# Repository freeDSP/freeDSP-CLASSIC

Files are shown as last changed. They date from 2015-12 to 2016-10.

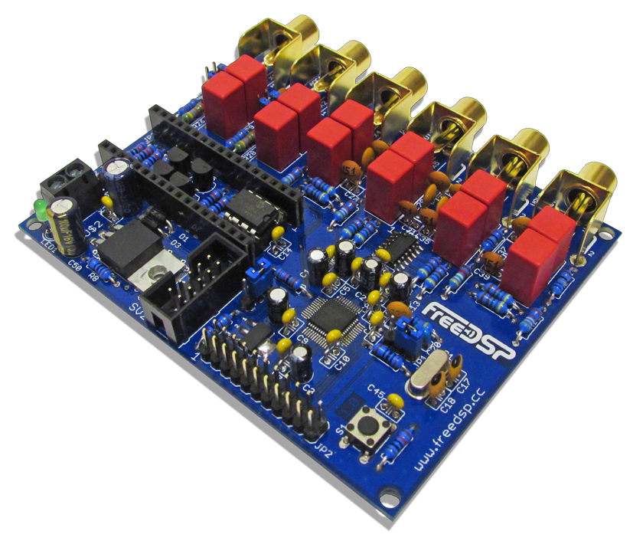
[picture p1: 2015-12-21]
DOCUMENTATION/PICTURES/freeDSP_1_0_side.png

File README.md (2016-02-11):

# freeDSP CLASSIC

BOARD STATUS: READY TO BE BUILT

MAIN COORDINATOR: [sudlud](https://github.com/sudlud)

The freeDSP CLASSIC is a cost-effective real-time audio signal processing solution for researchers and the do-it-yourself community. It is a bare circuit board that can be incorporated into your own projects. It comes with no housing. Easy assembling and simple programmability are the main focus. It is based on Analog Devices’ ADAU1701 DSP chip together with the free graphical development environment SigmaStudio. The programming model is function-block based – comparable to other graphical programming languages like PureData or Max/MSP. Many prebuilt blocks (e.g., filters, compressors, effects, or logic) can be placed in the signal path via drag and drop. If the included libraries do not have the functions needed, low-level blocks, such as multipliers and delays, can be wired together to create custom algorithms.

This board uses MAINLY THT components. The trickiest part is soldering the DSP, which comes in an SMD packaging. A complete SMD version is under development.

## Features

The freeDSP CLASSIC board offers two analog inputs and four analog outputs. Compared to other DSP solutions with easy programmability, the freeDSP and SigmaStudio offer a much wider range of DSP processing options and interface controls. It can be used in various audio applications, e.g.:

* Room compensation / system equalization
* Digital crossovers in active loudspeaker concepts
* Multiband dynamics processing
* Delay compensation / phase shift
* Bass enhancement
* Subwoofer integration
* Advanced instrument audio effect units
* Stereo image widening
…

For more information, please refer to the website www.freeDSP.cc and the documentation.  

## License

This work and all other materials under https://github.com/freeDSP are licensed under a <a rel="license" href="http://creativecommons.org/licenses/by-sa/4.0/legalcode">Creative Commons Attribution Share-Alike 4.0 license</a>. This allows for both personal and commercial derivative works, as long as they credit freeDSP and release their designs under the same license.

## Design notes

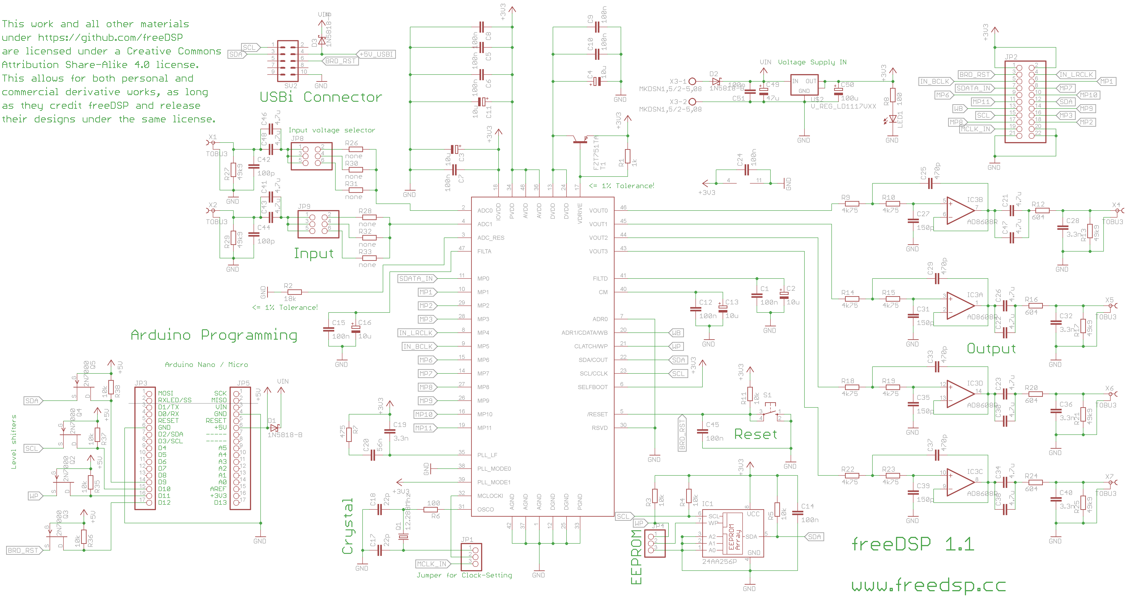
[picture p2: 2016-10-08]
SOURCES/EAGLE/SCHEMATIC_FREEDSP_V1_1_300dpi.png

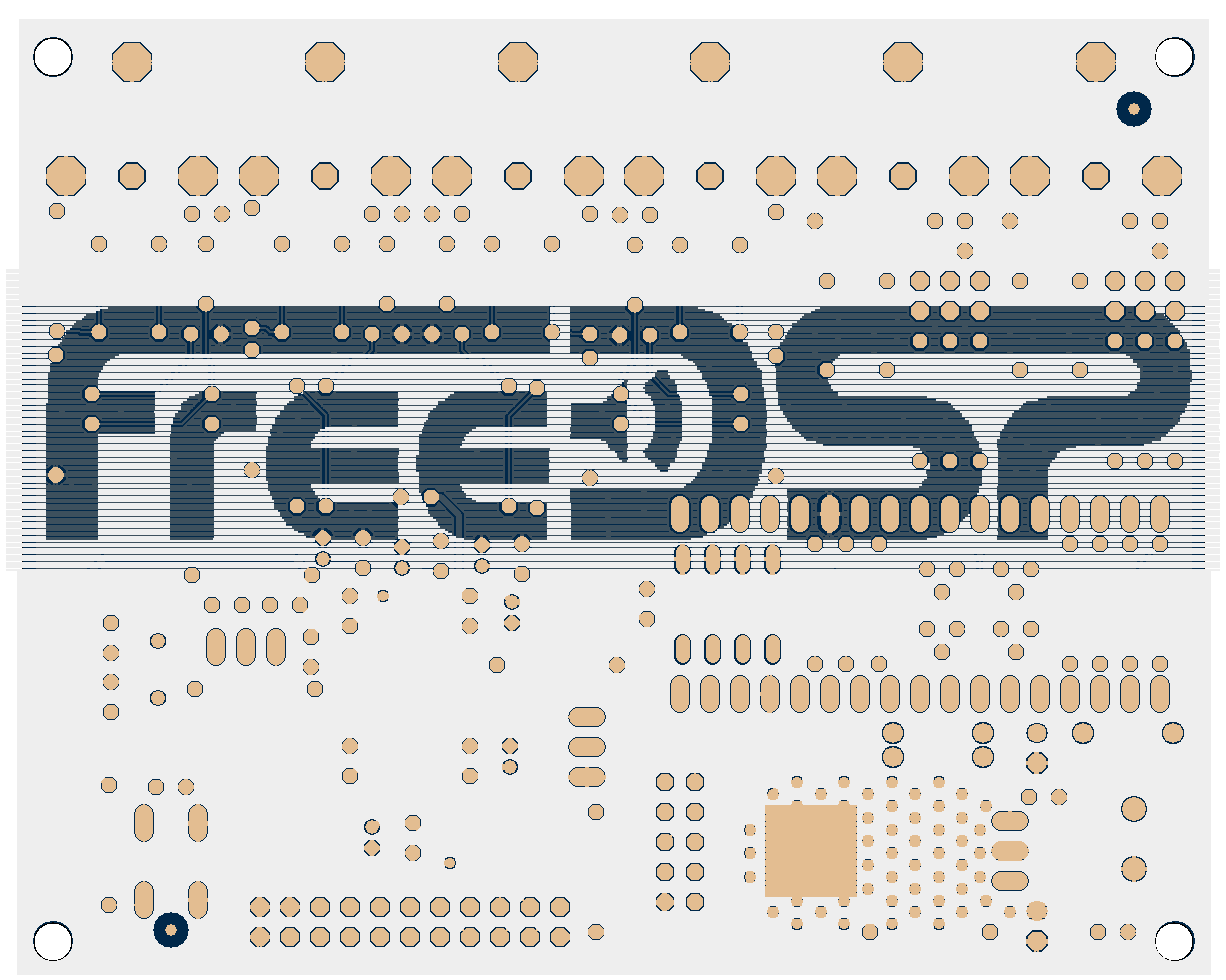
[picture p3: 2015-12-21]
DOCUMENTATION/PICTURES/back.png

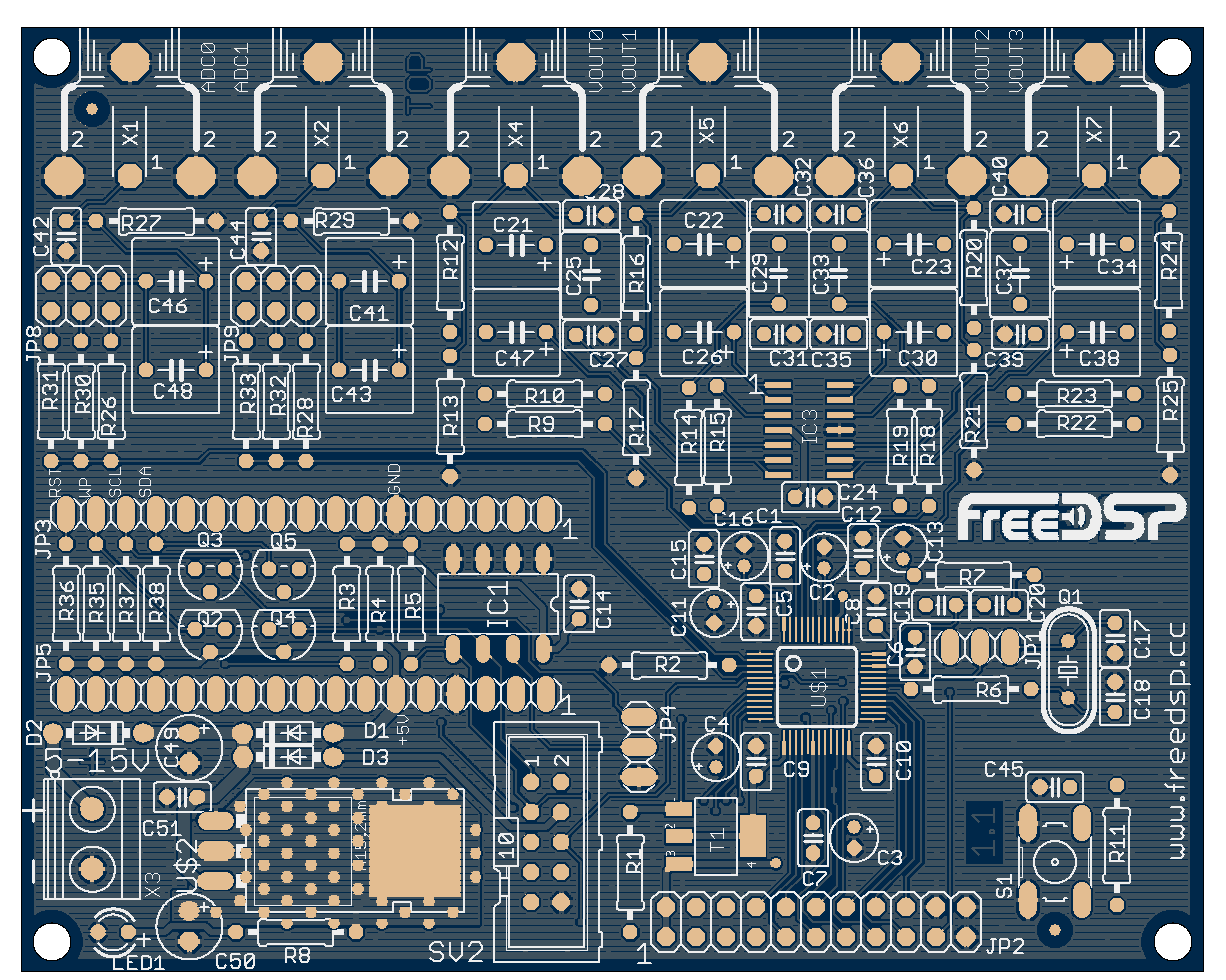
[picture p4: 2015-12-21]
DOCUMENTATION/PICTURES/front.png

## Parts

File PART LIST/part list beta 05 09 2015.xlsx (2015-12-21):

Part list |  |  |  | reichelt.de
Part | Description | Label | Qty. | Order number
C1, C5, C6, C7, C8, C9, C10, C12, C14, C15, C24, C45, C51 | Ceramic capacitor, 100nF | 104 | 13 | X7R-2,5 100N
C2, C3, C4, C11, C13, C16 | Electrolytic capacitor, radial, 10µF, 16V/50V | 10µF/16 | 6 | SM 10/16 RAD
C17, C18 | Ceramic capacitor, 22pF, 63V/200V | 22/100V | 2 | KERKO 22P
C19, C28, C32, C36, C40 | Ceramic capacitor, 3.3nF, 63V/50V | 332 | 5 | KERKO 3,3N
C20 | Ceramic capacitor, 56nF, 100V | green blue orange | 1 | not available
C21, C22, C23, C26, C30, C34, C38, C41, C43, C46, C47, C48 | Foil capacitor, 4.7µF | 4,7µF | 12 | MKS-2 4,7µ
C25, C29, C33, C37 | Ceramic capacitor, 470pF, 500V | 470 | 4 | KERKO-500 470P
C27, C31, C35, C39 | Ceramic capacitor, 150pF, 63V | 151 | 4 | KERKO 150P
C42, C44 | Ceramic capacitor, 100pF, 50V | 101 | 2 | KERKO 100P
C49 | Electrolytic capacitor, radial, 47µF, 35V | 47µF/35 | 1 | RAD 47/35
C50 | Electrolytic capacitor, radial, 100µF, 6.3V | 100µF/16 | 1 | RAD FC 100/16
D1, D2, D3 | Shottky diode, 1N5818, DO41, 30V, 1A | 1N5818 | 3 | 1N 5818
IC1a | EEPROM, serial, 256kBit, DIP-8 | 24AA256 | 1 | 24AA256-I/P
IC1b | IC socket, DIP8 (for EEPROM) | - | 1 | GS 8
IC3 | AD8608 | AD8608 | 1 | Order via DigiKey
JP1, JP4 | Multi-pin connector, 1x3, RM 2.54mm | - | 2 | MPE 087-1-003
JP2 | Multi-pin connector, 2x13, RM 2.54mm, needs to be shortened to 2x11 | - | 1 | SL 2x13G 2,54
JP3, JP5 | Plug connector, 1x20, RM 2.54mm, needs to be shortened to 1x17 | - | 2 | BL 1x20G8 2,54
JP8, JP9 | Multi-pin connector, 2x3, RM 2.54mm | - | 2 | MPE 087-2-006
LED1 | LED, 3mm, green | - | 1 | LED 3MM 2MA GN
Q1 | Quartz crystal, 12.288Mhz, HC49/U-S | - | 1 | 12,2880-HC49U-S
Q2, Q3, Q4, Q5 | n-MOSFET 2N7000 | - | 4 | 2N 7000
R1 | Resistor, 1kΩ | brown black black brown brown | 1 | METALL 1,00K
R2, R26, R28 | Resistor, 18kΩ | brown grey black red brown | 3 | METALL 18,0K
R3, R4, R5, R11, R35, R36, R37, R38 | Resistor, 10kΩ | brown black black red brown | 8 | METALL 10,0K
R6, R8 | Resistor, 100Ω | brown black black black brown | 2 | METALL 100
R7 | Resistor, 475Ω | yellow violet green black brown | 1 | METALL 475
R9, R10, R14, R15, R18, R19, R22, R23 | Resistor, 4.75kΩ | yellow violet green brown brown | 8 | METALL 4,75k
R12, R16, R20, R24 | Resistor, 604Ω | blue black yellow black brown | 4 | METALL 604
R13, R17, R21, R25, R27, R29 | Resistor, 49.9kΩ | yellow white white red brown | 6 | METALL 49,9K
R31, R33 | Resistor, 7.15kΩ | violet brown green brown brown | 2 | METALL 7,15K
R30, R32 | Resistor, 10.5kΩ | brown black green red brown | 2 | METALL 10,5K
S1 | Switch, 6x6mm, H: 4.3mm; 12V | - | 1 | TASTER 3301
SV2 | Boxed header, 10 pins | - | 1 | WSL 10G
T1 | Zetex PNP transistor | - | 1 | FZT 751TA
U1 | ADAU1701 | - | 1 | Order via DigiKey
U2 | LM1117 +3V3 voltage regulator | - | 1 | LM 1117 T3,3
X1, X2, X4, X5, X6, X7 | Cinch connector | - | 6 | CBP-G
JP1, JP4, JP8, JP9 | Jumper | - | 4 | JUMPER 2,54 BL
X3 | Terminal, 2x, 5.08mm grid | - | 1 | AKL 101-02

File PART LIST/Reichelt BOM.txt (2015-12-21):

http://www.reichelt.de/?ACTION=20;AWKID=1038022;PROVID=2084

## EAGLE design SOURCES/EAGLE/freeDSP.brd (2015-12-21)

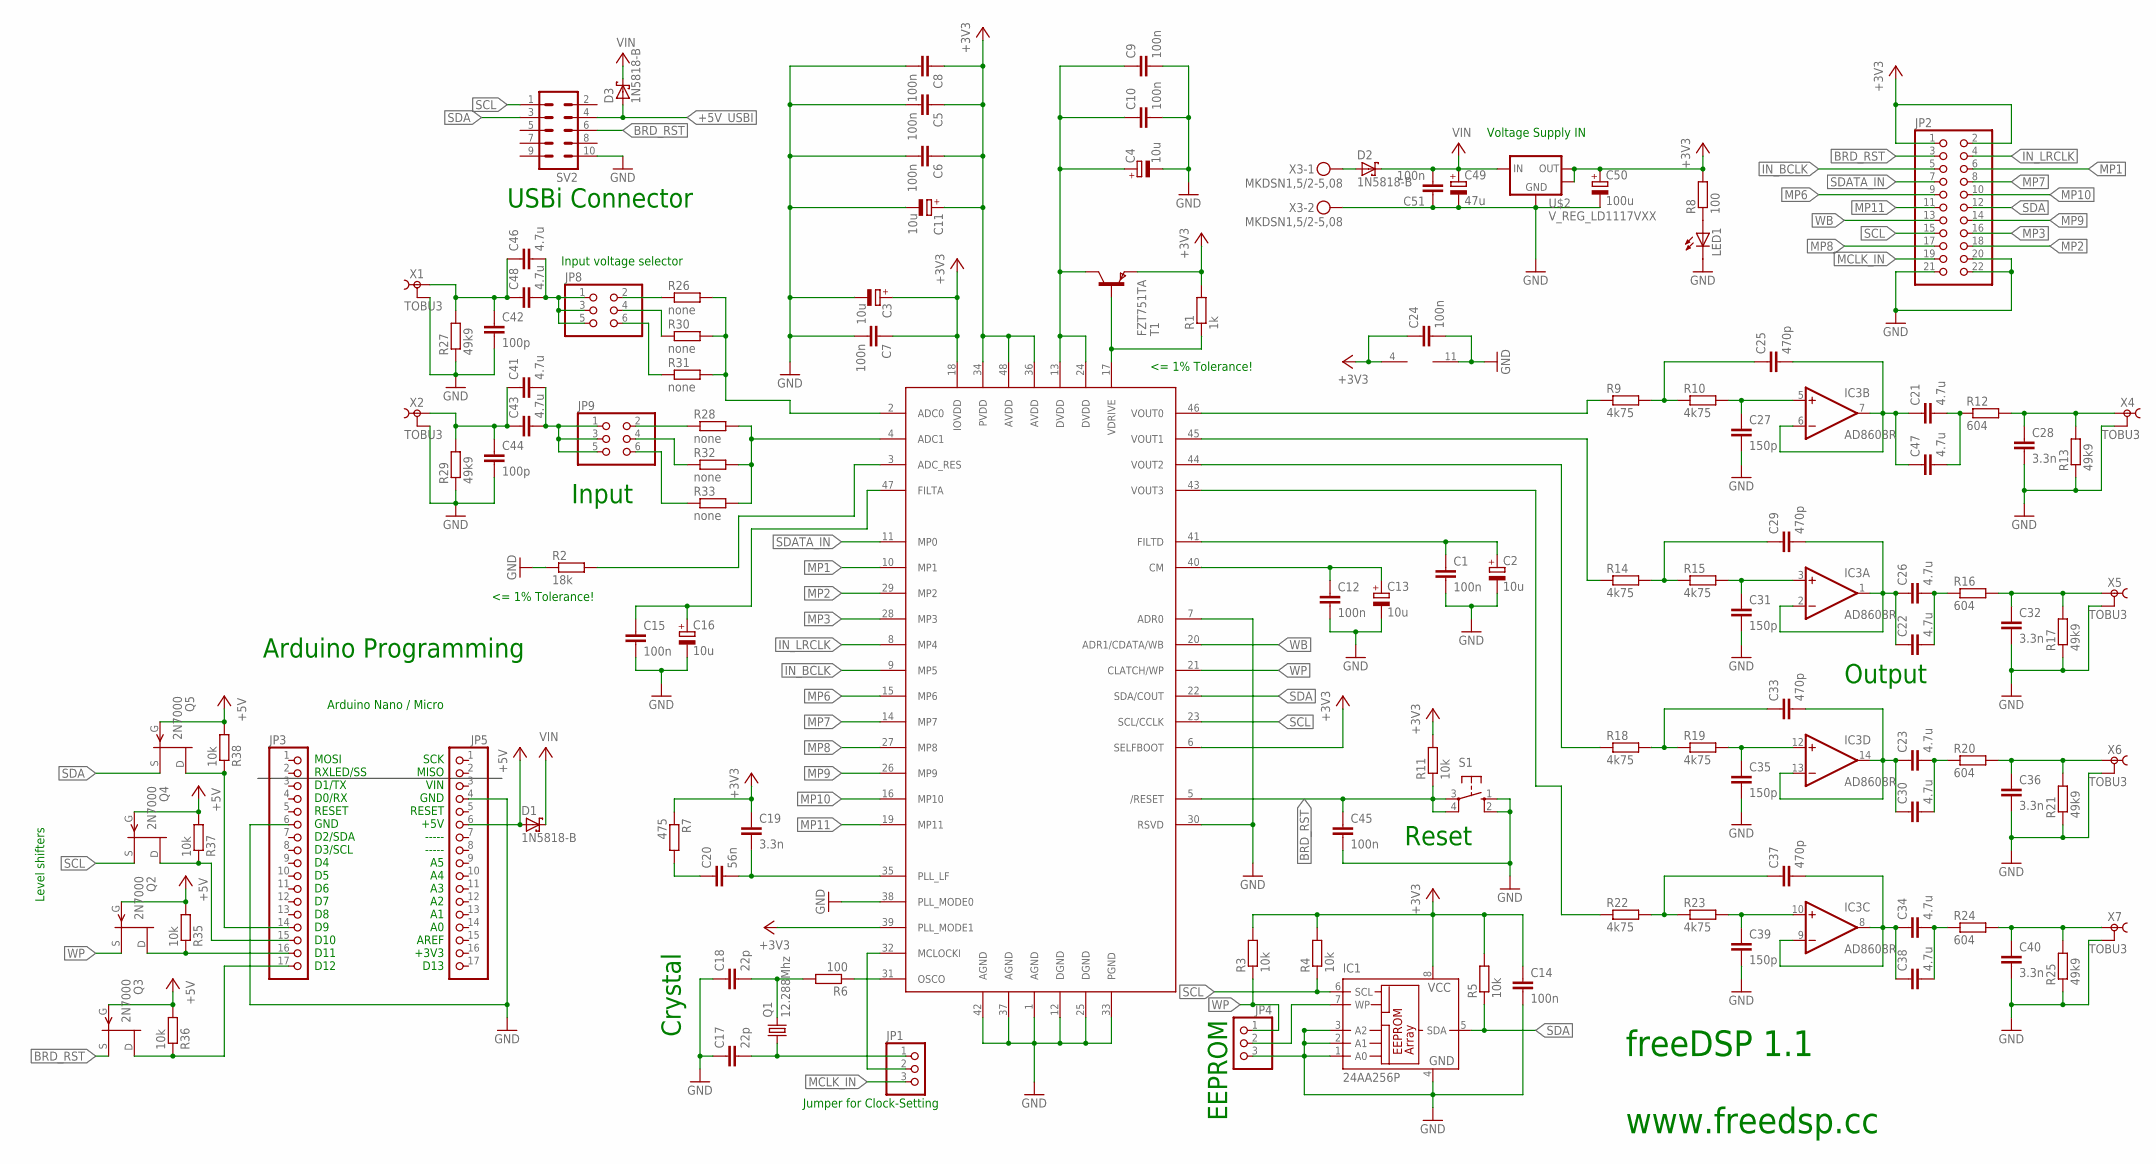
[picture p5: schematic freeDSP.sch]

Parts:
C1, C5, C6, C7, C8, C9, C10, C12, C14, C15, C24, C45, C51: 100n; C025-025X050
C2, C3, C4, C11, C13, C16: 10u; E1,8-4
C17, C18: 22p; C025-025X050
C19, C28, C32, C36, C40: 3.3n; C025-025X050
C20: 56n; C025-025X050
C21, C22, C23, C26, C30, C34, C38, C41, C43, C46, C47, C48: 4.7u; C050-075X075
C25, C29, C33, C37: 470p; C050-050X075
C27, C31, C35, C39: 150p; C025-025X050
C42, C44: 100p; C025-025X050
C49: 47u; E2,5-6
C50: 100u; E2,5-6
D1, D2, D3: 1N5818-B; DO41-7.6
IC1: 24AA256P; DIL8
IC3: AD8608R; SO-14
JP1, JP4: PINHD-1X3; 1X03
JP2: PINHD-2X11; 2X11
JP3, JP5: PINHD-1X17; 1X17
JP8, JP9: PINHD-2X3; 2X03
LED1: LED3MM
Q1: 12.288Mhz; HC49/S
Q2, Q3, Q4, Q5: 2N7000; TO92
R1: 1k; 0207/10
R2: 18k; 0207/10
R3, R4, R5, R11, R35, R36, R37, R38: 10k; 0207/10
R6, R8: 100; 0207/10
R7: 475; 0207/10
R9, R10, R14, R15, R18, R19, R22, R23: 4k75; 0207/10
R12, R16, R20, R24: 604; 0207/10
R13, R17, R21, R25, R27, R29: 49k9; 0207/10
R26, R28, R30, R31, R32, R33: none; 0207/10
S1: 10-XX; B3F-10XX
SV2: ML10
T1: FZT751TA; SOT223
U$1: ADAU1701; LQFP-48
U$2: V_REG_LD1117VXX; 78XXL
X1, X2, X4, X5, X6, X7: TOBU3
X3: MKDSN1,5/2-5,08

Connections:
1V8: C4.+, C9.1, C10.1, T1.2 (C), T1.4 (C), U$1.13 (DVDD), U$1.24 (DVDD)
+3V3: C3.+, C5.1, C6.1, C7.1, C8.1, C11.+, C14.1, C19.1, C24.1, C50.+, IC1.8 (VCC), IC3.4 (V+), JP2.1, JP2.2, R1.2, R3.2, R4.2, R5.2, R7.1, R8.2, R11.2, T1.3 (E), U$1.6 (SELFBOOT), U$1.18 (IOVDD), U$1.34 (PVDD), U$1.36 (AVDD), U$1.39 (PLL_MODE1), U$1.48 (AVDD), U$2.GND (OUT), U$2.OUT2
+5V: D1.A, JP5.6, Q2.2 (G), Q3.2 (G), Q4.2 (G), Q5.2 (G), R35.2, R36.2, R37.2, R38.2
+5V_USBI: D3.A, SV2.4
ADC0: R28.2, R32.2, R33.2, U$1.4 (ADC1)
BRD_RST: C45.1, JP2.3, Q3.3 (S), R11.1, S1.3, S1.4 (P1), SV2.6, U$1.5 (/RESET)
CM: C12.1, C13.+, U$1.40 (CM)
FILTA: C15.1, C16.+, U$1.47 (FILTA)
FILTD: C1.1, C2.+, U$1.41 (FILTD)
FILTOUT0: C28.1, R12.2, R13.2, X4.1
FILTOUT1: C32.1, R16.2, R17.2, X5.1
FILTOUT2: C36.1, R20.2, R21.2, X6.1
FILTOUT3: C40.1, R24.2, R25.2, X7.1
GND: C1.2, C2.-, C3.-, C4.-, C5.2, C6.2, C7.2, C8.2, C9.2, C10.2, C11.-, C12.2, C13.-, C14.2, C15.2, C16.-, C17.1, C18.1, C24.2, C27.2, C28.2, C31.2, C32.2, C35.2, C36.2, C39.2, C40.2, C42.2, C44.2, C45.2, C49.-, C50.-, C51.1, IC1.1 (A0), IC1.2 (A1), IC1.3 (A2), IC1.4 (GND), IC3.11 (V-), JP2.20, JP2.21, JP2.22, JP3.6, JP4.3, JP5.4, LED1.K (C), R2.1, R13.1, R17.1, R21.1, R25.1, R27.1, R29.1, S1.1 (S), S1.2 (S1), SV2.10, U$1.1 (AGND), U$1.7 (ADR0), U$1.12 (DGND), U$1.25 (DGND), U$1.30 (RSVD), U$1.33 (PGND), U$1.37 (AGND), U$1.38 (PLL_MODE0), U$1.42 (AGND), U$2.IN (GND), X1.2, X1.2@1 (2), X1.2@2 (2), X2.2, X2.2@1 (2), X2.2@2 (2), X3.2, X4.2, X4.2@1 (2), X4.2@2 (2), X5.2, X5.2@1 (2), X5.2@2 (2), X6.2, X6.2@1 (2), X6.2@2 (2), X7.2, X7.2@1 (2), X7.2@2 (2)
IN_BCLK: JP2.5, U$1.9 (MP5)
IN_LRCLK: JP2.4, U$1.8 (MP4)
MCLK_IN: JP1.3, JP2.19
MP1: JP2.6, U$1.10 (MP1)
MP2: JP2.18, U$1.29 (MP2)
MP3: JP2.16, U$1.28 (MP3)
MP6: JP2.9, U$1.15 (MP6)
MP7: JP2.8, U$1.14 (MP7)
MP8: JP2.17, U$1.27 (MP8)
MP9: JP2.14, U$1.26 (MP9)
MP10: JP2.10, U$1.16 (MP10)
MP11: JP2.11, U$1.19 (MP11)
unnamed: R2.2, U$1.3 (ADC_RES)
unnamed: R1.1, T1.1 (B), U$1.17 (VDRIVE)
unnamed: C19.2, C20.2, U$1.35 (PLL_LF)
unnamed: C23.1, C30.1, C33.2, IC3.13 (-IN), IC3.14 (OUT)
unnamed: C20.1, R7.2
unnamed: C18.2, Q1.2, R6.2
unnamed: C17.2, JP1.1, Q1.1
unnamed: R6.1, U$1.31 (OSCO)
unnamed: LED1.A, R8.1
unnamed: JP1.2, U$1.32 (MCLOCKI)
unnamed: JP3.15, Q4.1 (D), R37.1
unnamed: C21.2, C47.2, R12.1
unnamed: C29.1, R14.2, R15.1
unnamed: JP3.14, Q5.1 (D), R38.1
unnamed: C22.1, C26.1, C29.2, IC3.1 (OUT), IC3.2 (-IN)
unnamed: C31.1, IC3.3 (+IN), R15.2
unnamed: C25.1, R9.2, R10.1
unnamed: C21.1, C25.2, C47.1, IC3.6 (-IN), IC3.7 (OUT)
unnamed: C22.2, C26.2, R16.1
unnamed: C27.1, IC3.5 (+IN), R10.2
unnamed: C33.1, R18.2, R19.1
unnamed: C23.2, C30.2, R20.1
unnamed: JP3.16, Q2.1 (D), R35.1
unnamed: C35.1, IC3.12 (+IN), R19.2
unnamed: JP3.17, Q3.1 (D), R36.1
unnamed: C37.1, R22.2, R23.1
unnamed: C34.1, C37.2, C38.1, IC3.8 (OUT), IC3.9 (-IN)
unnamed: C39.1, IC3.10 (+IN), R23.2
unnamed: C34.2, C38.2, R24.1
unnamed: C46.2, C48.2, JP8.1, JP8.3, JP8.5
unnamed: C42.1, C46.1, C48.1, R27.2, X1.1
unnamed: JP8.2, R26.1
unnamed: JP8.4, R30.1
unnamed: C41.1, C43.1, C44.1, R29.2, X2.1
unnamed: JP8.6, R31.1
unnamed: C41.2, C43.2, JP9.1, JP9.3, JP9.5
unnamed: JP9.2, R28.1
unnamed: JP9.4, R32.1
unnamed: JP9.6, R33.1
unnamed: R26.2, R30.2, R31.2, U$1.2 (ADC0)
unnamed: D2.A, X3.1
unnamed: IC1.7 (WP), JP4.2
SCL: IC1.6 (SCL), JP2.15, Q4.3 (S), R4.1, SV2.1, U$1.23 (SCL/CCLK)
SDA: IC1.5 (SDA), JP2.12, Q5.3 (S), R5.1, SV2.3, U$1.22 (SDA/COUT)
SDATA_IN: JP2.7, U$1.11 (MP0)
V+: C49.+, C51.2, D1.C, D2.C, D3.C, U$2.OUT (IN)
VOUT0: R9.1, U$1.46 (VOUT0)
VOUT1: R14.1, U$1.45 (VOUT1)
VOUT2: R18.1, U$1.44 (VOUT2)
VOUT3: R22.1, U$1.43 (VOUT3)
WB: JP2.13, U$1.20 (ADR1/CDATA/WB)
WP: JP4.1, Q2.3 (S), R3.1, U$1.21 (CLATCH/WP)

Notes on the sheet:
<= 1% Tolerance!
EEPROM
Jumper for Clock-Setting
Crystal
Reset
Output
Input
Input voltage selector
USBi Connector
Arduino Programming
Voltage Supply IN
Arduino Nano / Micro
MOSI RXLED/SS D1/TX D0/RX RESET GND D2/SDA D3/SCL D4 D5 D6 D7 D8 D9 D10 D11 D12
SCK MISO VIN GND RESET +5V ----- ----- A5 A4 A3 A2 A1 A0 AREF +3V3 D13
Level shifters
freeDSP 1.1 www.freedsp.cc

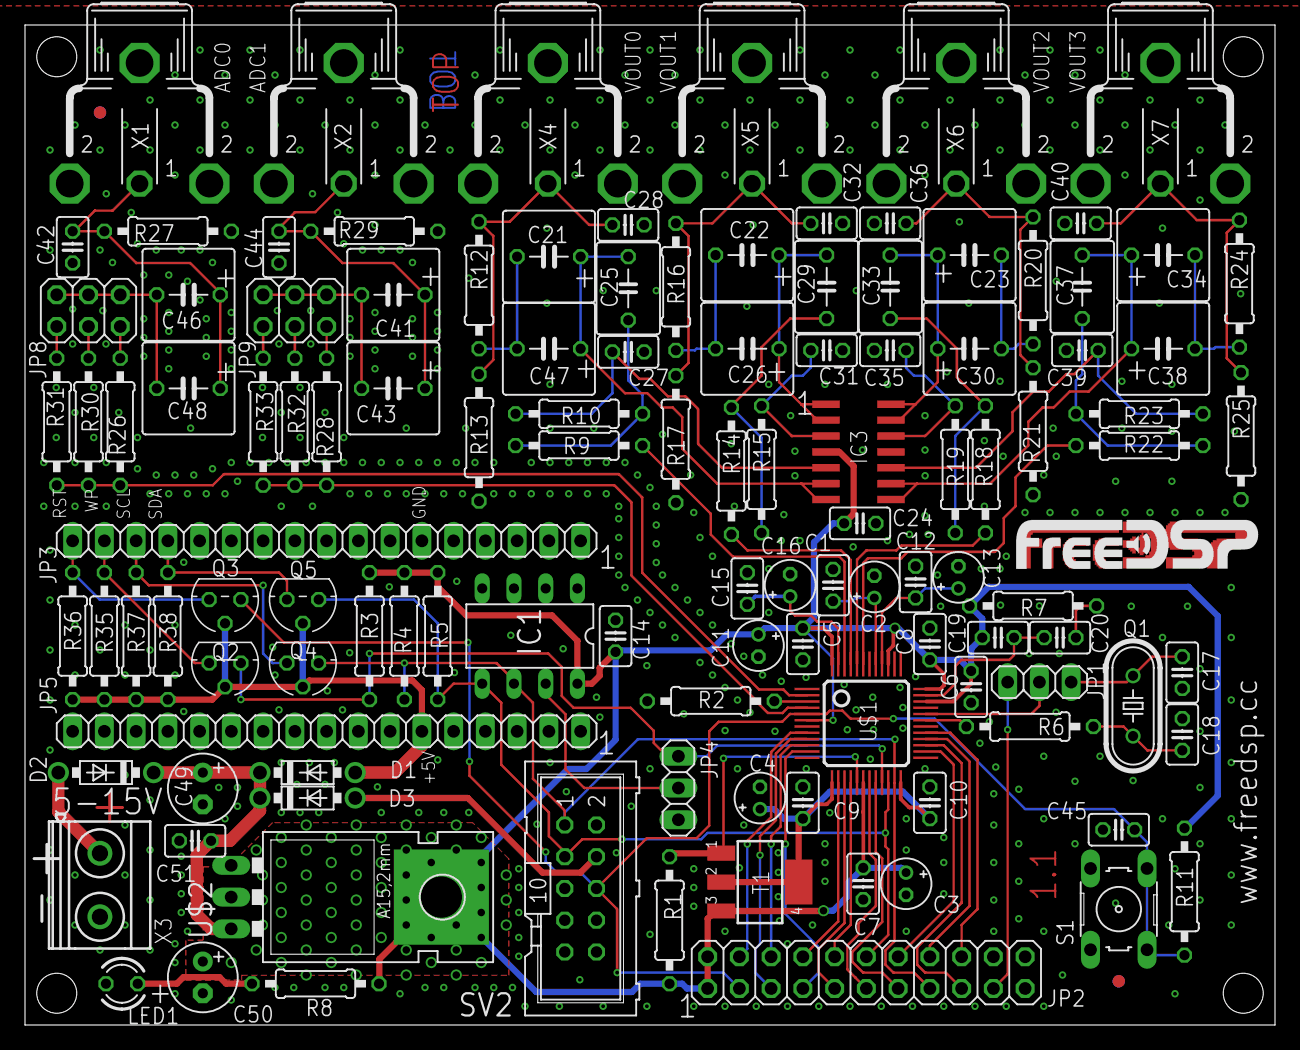
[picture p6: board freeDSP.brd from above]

Board: 2 copper layers, 100.0 x 80.0 mm, 120 parts (0 on the bottom side), 78 nets.

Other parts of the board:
U$3, U$4: VISION_REF10

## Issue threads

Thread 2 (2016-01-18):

Upgrade for Output Filter

sudlud, 2016-01-18:
Output filters:
* recalculation of cutoff-frequency
 * measure intensity of alias-frequencies (signal path: anallog in --> dsp --> analog out)
 * based on different sampling-frequencies
* swap opamp
 * better opamp with single supply (ad8656, expensive)
 * better opamp with dual supply (ne5532, good & cheap)
* define phase-requirements

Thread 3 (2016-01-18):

Upgrade for Input Filter

sudlud, 2016-01-18:
Input filters:
* recalculation and redesign based on different sampling-frequencies

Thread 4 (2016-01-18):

Power Supply Redesign for Dual Supply

sudlud, 2016-01-18:
Power Supply:
* redesign to feed external boards with +12V
* redesign for dual supply (+-12V/+-9V)

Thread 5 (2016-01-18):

Sampling-Frequencies limited to 48kHz?

sudlud, 2016-01-18:
* sampling frequencies of adc and dac?
* diyaudio.com: user basreflex mentioned, that adc & dac will always run on 48 kHz, only the core will run on higher sample rates (?)

(no source provided yet)

basreflex, 2016-01-23:
from AD's engineerzone
""
Conversely, if you are running at 96 kHz, the MCLK frequency itself remains unchanged, and you're simply doubling the rate of the DSP core and converter filters. In that case, you only need to change a register setting, and no hardware changes are required.

In summary, the ADC_RES values for 48 kHz and 96 kHz should be the same, because the core clock frequencies are the same in both cases.

In retrospect, the datasheet does a poor job of explaining this. I will make this into a FAQ on EngineerZone in order to help clear up any confusion on the subject.

so the ADC is not running faster, it could be that the decimator is being adjusted, by my guess is that the decimator and postfilter is fixed and the 96k this signal is just doubly sampled.

the noise floor plot of the DAC out of a signal sampled by the ADC shows a 0-20khz elevated floor, then a lower DAC floor from 20-100khz and a residue at 48khz even when the processor is running at 96kHz.

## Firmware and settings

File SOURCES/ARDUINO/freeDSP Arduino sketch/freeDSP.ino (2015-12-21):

/*
130232 Universal Through-hole Audio DSP board
(c) Elektor, 12/2013
Author: CPV

This is a sketch to quickly program the I2C EEPROM on the Elektor
130232-1 Audio DSP board. 

0. Install the Arduino libraries EEPROM24, I2CMaster & SoftI2C.

1. Load the sketch to the Arduino board.

2. Connect connector K9 to an Arduino Uno or Mega, like this:

   K9   | Arduino
   -----+--------
   SDA  |   9
   SCL  |   10
   WP   |   11
   RST  |   12
   GND  |   GND
   
3. Do not place jumper JP1 of the DSP board. 
   
4. Send the E2Prom.hex file generated in SigmaStudio to the 
   Arduino board. The baudrate is 19200 baud. The DSP board
   must be powered.
   
License: identical as EEPROM24, I2CMaster & SoftI2C.
*/

/*
Modified by Ludwig Kormann

Changes made to work with freeDSP

31.08.2014
*/

/*Modified by Tom Wuehle

-changed baudrate from 19200 to 9600 to meet defaults from Tera Term
-added initial delay for easier serial setup with arduino micro

20.04.2015
*/

#include <EEPROM24.h>
#include <I2CMaster.h>
#include <SoftI2C.h>

#define SOFT_SDA  9
#define SOFT_SCL  10
const int write_protect_pin = 11;
const int reset_pin = 12;

SoftI2C i2c(SOFT_SDA,SOFT_SCL); // SDA=10, SCL=11
EEPROM24 eeprom(i2c,EEPROM_24LC256);

uint8_t in_buffer[128]; // Largest possible page size.
size_t in_buffer_index = 0;
uint32_t dst_address = 0;
int rx_state = 0;
uint32_t timeout = 0;
const uint32_t baudrate = 9600;
uint32_t bytes_received = 0;
boolean busy = false;

// States for main loop
enum states{
  STATE_RESET_DSP,
  STATE_RUNNING
} availableStates;

uint8_t state = STATE_RESET_DSP;

void print_hex_char(uint8_t ch)
{
  Serial.print((ch>>4)&0x0f,HEX);
  Serial.print(ch&0x0f,HEX);
}

void print_buffer(uint8_t *p_data, size_t data_size)
{
  for (uint8_t i=0; i<data_size; i++)
  {
    print_hex_char(p_data[i]);
  }
  Serial.println();
}

uint8_t hex_to_bin(uint8_t ch)
{
  if (ch>='0' && ch<='9') return ch - '0'; // 0-9
  else if (ch>='A' && ch<='F') return ch - 'A' + 10; // 10-15
  else if (ch>='a' && ch<='f') return ch - 'a' + 10; // 10-15
  return 0;
}

void resetDSP(void)
{ 
  // Disconnect all signals
  pinMode(write_protect_pin, INPUT);
  pinMode(SOFT_SDA, INPUT);
  pinMode(SOFT_SCL, INPUT);
  
  // Perform Reset
  pinMode(reset_pin, OUTPUT);
  digitalWrite(reset_pin,0);
  delay(250);
  pinMode(reset_pin, INPUT);
}

void initVariables(void)
{
 // Reinitialize variables
  busy = false;
  rx_state = 0;
  in_buffer_index = 0;
  dst_address = 0;
  bytes_received = 0;
  timeout = millis();  
}

void setup(void)
{
  Serial.begin(baudrate);
  while (!Serial) {
    ; // wait for serial port to connect.
  }
  Serial.println("Elektor Project 130232 Audio DSP Board");
  Serial.println("EEPROM Programmer");
  Serial.print("eeprom ");
  if (eeprom.available()==false) Serial.print("not ");
  Serial.println("found");
  
  state = STATE_RESET_DSP;
}

void loop(void)
{
  switch(state)
  {
    case STATE_RESET_DSP:
      initVariables();
      resetDSP();
      Serial.println("waiting for E2Prom.Hex file...");
      state = STATE_RUNNING;
      break;
      
    case STATE_RUNNING:
        if (busy==true && millis()-timeout>500)
        {
          // Serial port idle too long, consider file transfer done.
          // Write any remaining data to eeprom.
          eeprom.write(dst_address,in_buffer,in_buffer_index);
          Serial.print("Received ");
          Serial.print(bytes_received);
          Serial.println(" characters");
          Serial.print("Programmed ");
          Serial.print(dst_address+in_buffer_index);
          Serial.println(" bytes");
          Serial.println();
          
          // Read programmed data back to serial port.
          Serial.println("EEPROM contents:");
          uint16_t i = 0;
          while (i<dst_address+in_buffer_index)
          {
            eeprom.read(i,in_buffer,8);
            print_buffer(in_buffer,8);
            i += 8;
            if (i%eeprom.pageSize()==0) Serial.println();
          }
          
          // Get ready for a new file.
          state = STATE_RESET_DSP;
        }
        while (Serial.available()!=0)
        {
          if(!busy)
          {
            busy = true;
            initVariables();
            pinMode(SOFT_SDA, OUTPUT);
            pinMode(SOFT_SCL, OUTPUT);
            pinMode(reset_pin, OUTPUT);
            digitalWrite(reset_pin,LOW);
            pinMode(write_protect_pin, OUTPUT);
            digitalWrite(write_protect_pin,LOW);
          }
          busy = true;
          timeout = millis();
          uint8_t ch = Serial.read();
          bytes_received += 1;
          switch (rx_state)
          {
            case 0:
              if (ch=='x') rx_state = 1;
              else if (ch==0x0d || ch==0x0a) Serial.write(ch);
              break;
              
            case 1:
              in_buffer[in_buffer_index] = hex_to_bin(ch) << 4;
              rx_state = 2;
              break;
              
            case 2:
              in_buffer[in_buffer_index] += hex_to_bin(ch);
              print_hex_char(in_buffer[in_buffer_index]);
              in_buffer_index += 1;
              if (in_buffer_index==eeprom.pageSize())
              {
                eeprom.write(dst_address,in_buffer,in_buffer_index);
                dst_address += in_buffer_index;
                in_buffer_index = 0;
                Serial.println();
              }
              rx_state = 0;
              break;
          }
        }
      break;
    default:
      state = STATE_RESET_DSP;
      break;
  }
  
  
}

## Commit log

2015-12-21 folder structure + initial sources V1.1
    added folder structure + initial sources V1.1
    [freeDSP.brd, freeDSP.sch, part list beta 05 09 2015.xlsx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]
2016-10-08 Add licensing info to schematic & add PNG-Schematic
    This enables users to view the schematic without
    the need to download & install EAGLE on their
    computer.
    [freeDSP.sch]

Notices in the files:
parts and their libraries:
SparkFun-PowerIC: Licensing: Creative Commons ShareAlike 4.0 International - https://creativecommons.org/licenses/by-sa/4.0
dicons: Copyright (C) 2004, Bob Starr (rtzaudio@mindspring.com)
